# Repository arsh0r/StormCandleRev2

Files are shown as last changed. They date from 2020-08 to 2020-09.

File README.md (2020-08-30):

# StormCandleRev2 & Rev2b

An electronic candle measuring the air pressure and displaying it on a single, adressable RGBW LED.

An average air pressure is displayed by white light, high pressure in red and low pressure in blue.
The minimum and maximum pressure values are adapted automatically and stored in the EEPROM.

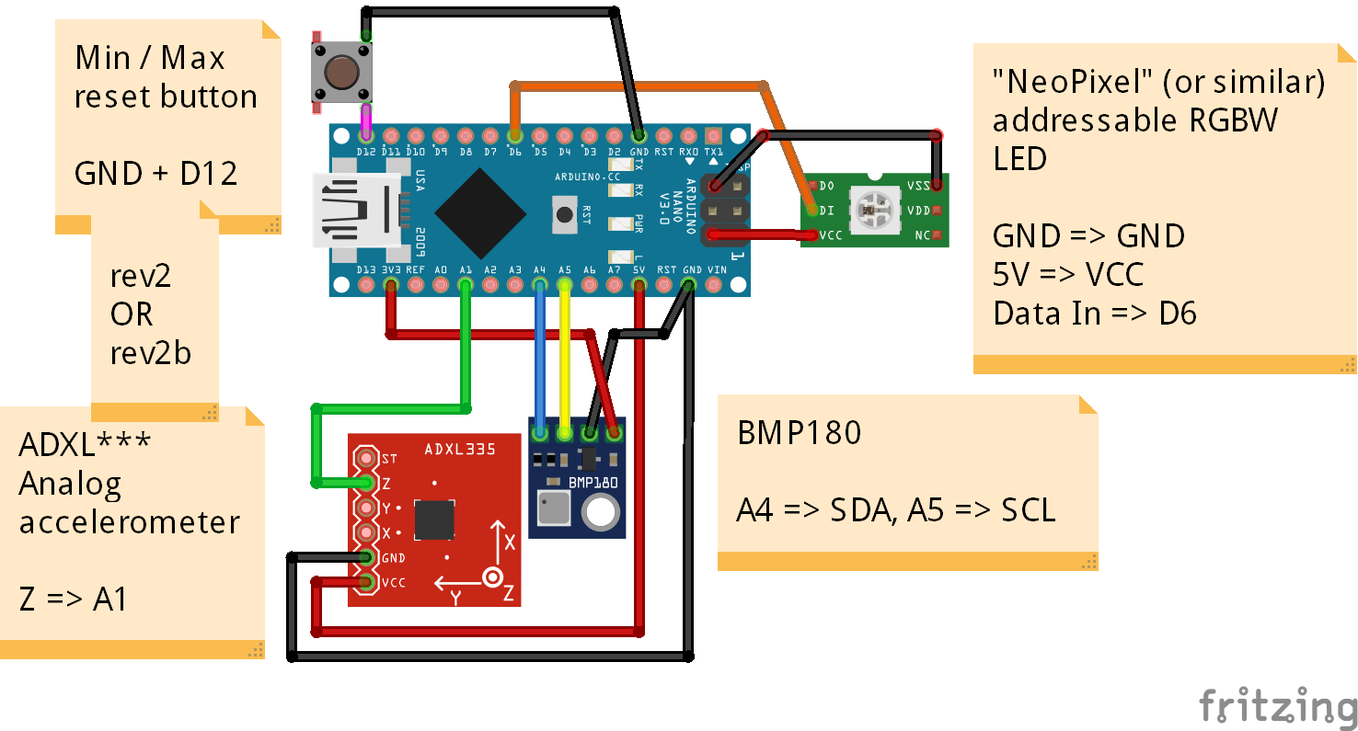
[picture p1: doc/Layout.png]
Frizzing sketch


This code works both with Revision 2 (reset button at the bottom) and Revision 2b (reset by accelerometer).

## Manuals

* [en English](/doc/manuals/en_manual.md)
* [de Deutsch](/doc/manuals/de_Benutzerhandbuch.md)

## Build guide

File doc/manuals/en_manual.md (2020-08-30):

# StormCandle User Manual
Thank you for ~~buying~~ building the StormCandle.

To help you enjoy your StormCandle, please read the following document carefully and follow its instructions.

## Understanding your StormCandle

Your StormCandle will show you the current air pressure as an intuitive color gradient.

It "remembers" the highest and lowes pressures it has ever experienced. At pressures in the centre between these values, it will glow warm white. 
At higher pressures, more and more red light is added, at lower pressures blue light. Since air pressure changes with altitude, 
you should perform a reset after any elevation change of more than one floor.

**Note:** If you operate the device in a roughly airtight environment such as a well-sealed house or appartment, 
you may accidentially change the air pressure when operating a strong range hood or other outward-facing ventilator. 
This may accidentially set a minimal pressure value far beneath the natural range and thus distort the displayed result. In this case, please perform a reset as explained below.

## Setup
To use the device, place it in a convenient location where you can see it and connect the USB plug to any USB power source (wall charger / USB power bank / computer). 
After first setup, you should perform a reset as described below.

### Resetting min / max values

#### Revision 2 (with reset button)
To perform a reset, first disconnect the device from power. Hold down the reset button (you may need to remove a cover at the bottom of the device to acces the button). While holding, connect the device to power and wait. 

#### Revision 2b (no reset button)
To perform a reset, first disconnect the device from power. Turn over the device and connect the device to power.

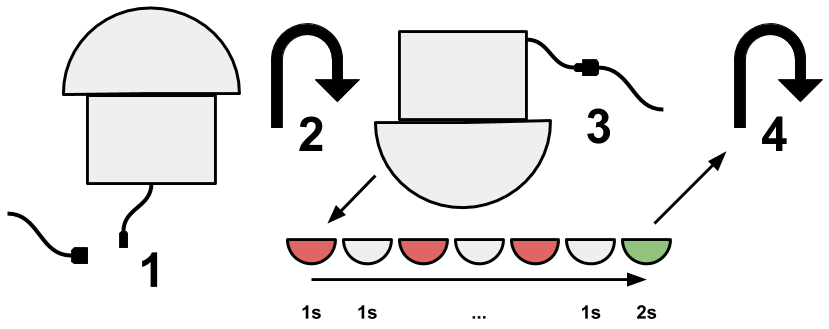
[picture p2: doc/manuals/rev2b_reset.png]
Rev2b reset process


The device will blink three times red (1 second) and once green (2 seconds). 
At the end of the green light, the device will be reset and start flickering white, blue and red.

## Technical information
Power consumption: ca. 50 mA @ 5 V

Source code: https://github.com/BitScout/StormCandleRev2

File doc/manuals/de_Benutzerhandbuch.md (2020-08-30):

# StormCandle Benutzerhandbuch
Herzlichen Glückwunsch zum ~~Kauf~~ Bau Ihrer StormCandle.
Damit Ihnen das Produkt viel Freude bereitet, lesen Sie bitte die folgenden Hinweise aufmerksam und befolgen Sie sie.

## Ihre StormCandle verstehen

Ihre StormCandle zeigt Ihnen den aktuellen Luftdruck intuitiv durch wechselnde Farben an.

Sie "merkt" sich den niedrigsten und höchsten Luftdruck, dem sie bisher ausgesetzt wurde.
Liegt  der Luftdruck genau mittig zwischen diesen Punkt leuchtet die StormCandle warmweiß.
Steigt der Luftdruck kommt stärker werdendes rotes Licht hinzu, bei niedrigerem Druck blaues Licht.
Da sich der Luftdruck mit der Höhe ändert, sollten Sie nach einer Ortsänderung des Gerätes von mehr als einem Stockwerk eine Rücksetzung vornehmen.

**Wichtig:** Falls Sie das Gerät in einem weitgehend luftdichten Umfeld wie z. B. einer Wohnung mit gut abgedichteten Fenstern und Türen betreiben, kann es passieren, dass beim Benutzen einer starken Dunstabzugshaube der Luftdruck deutlich unter das eigentliche Minimum fällt. Die StormCandle wird dies als neues Minimum registrieren und dementsprechend verfälschte Farben anzeigen. Bitte führen Sie in diesem Fall eine Rücksetzung wie unten beschrieben durch.

## Einrichtung
Zur Nutzung des Gerätes stellen Sie es bitte an einem gut einsehbaren Ort auf und verbinden Sie den USB-Stecker mit einer beliebigen USB-Stromquelle (USB-Ladegerät / Power Bank / Computer).
Nach der ersten Inbetriebnahme sollten Sie eine Rücksetzung durchführen (siehe unten).

### Höchst- und Tiefstwerte zurücksetzen

#### Revision 2 (Mit Reset-Knopf)
Um eine Rücksetzung durchzuführen, trennen Sie das Gerät bitte zunächst vom Strom. Halten Sie den Knopf an der Unterseite gedrückt. Ggf. müssen Sie hierzu eine Abdeckung entfernen. Während Sie den Knopf weiter gedrückt halten, verbinden Sie das Gerät mit der Stromzufuhr; halten Sie den Knopf weiter gedrückt.

#### Revision 2b (Ohne Reset-Knopf)
Um eine Rücksetzung durchzuführen, trennen Sie das Gerät bitte zunächst vom Strom. Drehen Sie die Lampe auf den Kopf und halten Sie sie so. Verbinden Sie das Gerät nun mit der Stromzufuhr.

Rev2b reset process

Die StormCandle blinkt dreimal rot (eine Sekunde Leuchtdauer) und anschließen einmal grün (zwei Sekunden). Sobald das grüne Licht erlischt sind die Höchst- und Tiefstwerte zurückgesetzt und die Lampe flackert in den Farben Warmweiß, Rot und Blau.
Das Flackern entsteht durch geringfügige Luftdruckschwankungen und lässt nach, sobald das Gerät höhere und niedriger Luftdrücke "erlernt" hat. Dies kann einige Stunden oder Tage dauern, während derer die Lampe **nicht** durchgehend in Betrieb sein muss.
Sie können das den Erfolg des Zurücksetzens testen, indem Sie die Lampe einen halben Meter anheben und absenken. Die Lichtfarbe sollte der Höhe entsprechend leicht rot bzw. blau werden.

## Technische Informationen
Energieverbrauch: ca. 50 mA @ 5 V (0,25 W)

Quellcode: https://github.com/BitScout/StormCandleRev2

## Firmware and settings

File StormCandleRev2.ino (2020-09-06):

// StormCandle Rev.2
// - For Ann -

// Displays the relative air pressure on a red (high) - blue (low) scale
// Self-learning, remembers the highest and lowest pressure it ever encountered
// Please perform a reset after significant elevation changes

// To reset the min/max values:
// 1. Power off the Arduino
// 2. Connect Pin 12 to ground (hold down the reset button)
// 3. Power on the Arduino
// 4. The LED will blink red three times
// 5. After one final green blink (2 seconds), the min/max values will be reset to just above and below the current measurement
// Note: With each reset, the memory addresses will be rotated through the EEPROM to reduce wear

// Connect the adressable RGBW LED to GND, to +5V and to PIN_LED

// Connect Arduino Nano -> pressure sensor BMP180
// A5  -> SCL
// A4  -> SDA
// GND -> GND
// VIN -> 3.3V

// EEPROM layout: (one letter = one byte)
// XXAAAABBBBCCCCDDDD
// I.L...L...L...L... (I = integer, L = long)
// XX   = Memory address
// AAAA = Minimum pressure at first run
// BBBB = Maximum pressure at first run
// CCCC = Minimum pressure after first reset
// DDDD = Maximum pressure after first reset
// etc.


#include <Wire.h>
#include <EEPROM.h>
#include <Adafruit_BMP085.h>
#include <Adafruit_NeoPixel.h>

Adafruit_BMP085 bmp;

//#define DEBUG 1

#define PIN_LED 6 // D6
#define PIN_RESET_EEPROM 12 // D12
#define PIN_ACCEL_Z A1
#define ACCEL_TRESHOLD 400
#define MEDIAN_COUNT 7 // Number of measurements per loop
#define STARTUP_RANGE 20 // Distance (in Pascale) between initial measurement and maximum / minimum at first startup
#define COLOR_BRIGHTNESS_FACTOR 1 // Make the color LEDs less bright
#define WHITE_BRIGHTNESS_FACTOR 0.1 // Make the white LED less bright

// Misc
int i;
int iMedian;
bool initializing = false;
unsigned long timestamp_last_readout;

bool firstrun = false; //first run;
float cycletime; //cycle time in [ms]
unsigned long micros_last; //last micros() in ms

// Pressures
long pa_measurements[MEDIAN_COUNT]; 
long pa_current;
float pa_current_PT1;
long pa_max;
long pa_min;
long pa_center;

// Manual inputs
bool switch_reset_eeprom;
int  acceleration_z;

// Addresses
int addr_int_addresses_start; // Start of the currently used address space
int addr_long_hpa_min;
int addr_long_hpa_max;
int address_block_end; // The first address after all used addresses

// LED
float led_max = 255;
int   red  = 0;
int   blue = 0;

Adafruit_NeoPixel strip = Adafruit_NeoPixel(1, PIN_LED, NEO_RGBW + NEO_KHZ800);


void setup() {
  setupHardware();

  timestamp_last_readout = millis();

  // First pressure measurement
  iMedian = MEDIAN_COUNT / 2;
  do {
    pa_current = bmp.readPressure();
  } while (pa_current < 900);

  EEPROM.get(0, addr_int_addresses_start);

  // Handle first launch
  if(-1 == addr_int_addresses_start) {
    initializing = true;
    addr_int_addresses_start = sizeof(int); // Leave the first two bytes in EEPROM for the start address of the min/max values
    EEPROM.put(0, addr_int_addresses_start);
  }

  // Check for reset button
  readResetSwitch();

  if(switch_reset_eeprom) {
    for(i = 0; i < 3; i++) {
      setColor(255, 0, 0, 0);
      delay(1000);
      setColor(0, 0, 0, 0);
      delay(1000);
    }

    // Read value again (to be sure)
    readResetSwitch();

    if(switch_reset_eeprom) {
      setColor(0, 255, 0, 0);
      delay(2000);

      // Add up all addresses as they were used before, then start after that. Addresses will be calculated again just below.
      calculateAddresses();
      addr_int_addresses_start = address_block_end;

      // Handle memory address wrap around
      if((E2END - 2*sizeof(long)) <= addr_int_addresses_start) {
        addr_int_addresses_start = sizeof(int);
      }
      
      EEPROM.put(0, addr_int_addresses_start); // Save the memory address to the beginning of the EEPROM memory
      initializing = true;
    }

      setColor(0, 0, 0, 0);
  }

  calculateAddresses();

  if(initializing) {
    #ifdef DEBUG
      Serial.println("Initializing EEPROM with current min/max values");
    #endif
    
    pa_max = pa_current + STARTUP_RANGE;
    pa_min = pa_current - STARTUP_RANGE;
    pa_center = pa_current;
    
    EEPROM.put(addr_long_hpa_min, pa_min);
    EEPROM.put(addr_long_hpa_max, pa_max);
  } else {
    #ifdef DEBUG
      Serial.println("Loading min/max values from EEPROM");
    #endif

    EEPROM.get(addr_long_hpa_min, pa_min);
    EEPROM.get(addr_long_hpa_max, pa_max);
  }

  calculateCenter();
  
  //init cycle time measurement
  micros_last = micros();
  firstrun = true;
}
  
void loop() {
  calcCycleTime();
  
  measureAndCalculatePT1();
  setLed();
  outputPressureOverSerial();

  #ifdef DEBUG
    //debugAddresses();
    //debugButton();
    //debugAcceleration();
    //debugLeds();
    debugPressures();
    Serial.println("");    
  #endif
  firstrun = false;
}

void setupHardware() {
  Serial.begin(9600);
  strip.begin();
  pinMode(PIN_RESET_EEPROM, INPUT_PULLUP);
  
  if (!bmp.begin()) {
    #ifdef DEBUG
      Serial.println("Sensor not found");
    #endif
    
    while (1) {}
  }
}

void calculateAddresses() {
  addr_long_hpa_min = addr_int_addresses_start;
  addr_long_hpa_max = addr_long_hpa_min + sizeof(long);
  address_block_end = addr_long_hpa_max + sizeof(long);
}

void readResetSwitch() {
  switch_reset_eeprom = !digitalRead(PIN_RESET_EEPROM);
  acceleration_z = analogRead(PIN_ACCEL_Z);

  if(acceleration_z > ACCEL_TRESHOLD) {
    switch_reset_eeprom = true;
  }
}

void measureAndCalculate() {
  // Collect measurements
  for (i = 0; i < MEDIAN_COUNT; i++) {
    do {
      pa_measurements[i] = bmp.readPressure();
    } while (pa_measurements[i] < 900);
  }

  // Sort measurements to find the median (center) value(s)
  bubbleSort();
  
  // Average the 3 central values to avoid excess flickering
  pa_current = (pa_measurements[iMedian] + pa_measurements[iMedian - 1] + pa_measurements[iMedian + 1]) / 3;

  // Calculate minimum, maximum and center values
  if(pa_current > pa_max) {
    pa_max = pa_current;
    EEPROM.put(addr_long_hpa_max, pa_max);
  }
  
  if(pa_current < pa_min) {
    pa_min = pa_current;
    EEPROM.put(addr_long_hpa_min, pa_min);
  }
  
  calculateCenter();
}

void calculateCenter() {
  pa_center = pa_min + (pa_max - pa_min) / 2;
}

void setLed() {
  // Set LED colours
  if (pa_current <= pa_center) red = 0; else red = led_max * (pa_current - pa_center) / (pa_max - pa_center);
  if (pa_current >= pa_center) blue = 0; else blue = led_max - (led_max * (pa_current - pa_min) / (pa_center - pa_min));

  setColor(red * COLOR_BRIGHTNESS_FACTOR, 0, blue * COLOR_BRIGHTNESS_FACTOR, led_max * WHITE_BRIGHTNESS_FACTOR);
}

void outputPressureOverSerial() {
  if(millis() - timestamp_last_readout > 60000) {
    timestamp_last_readout = millis();
    Serial.print(pa_current);
    Serial.println("");
  }
}

void setColor(int r, int g, int b, int w) {
  strip.setPixelColor(0, strip.Color(g, r, b, w));
  strip.show();
}

// Copied and adapted from https://www.tigoe.com/pcomp/code/arduinowiring/42/
void bubbleSort() {
  long out, in, swapper;
  
  for (out=0 ; out < MEDIAN_COUNT; out++) {
    for (in=out; in<(MEDIAN_COUNT-1); in++) {
      if ( pa_measurements[in] > pa_measurements[in+1] ) {
        swapper = pa_measurements[in];
        pa_measurements [in] = pa_measurements[in+1];
        pa_measurements[in+1] = swapper;
      }
    }
  }
}

void calcCycleTime() {
  unsigned long micros_current; //current lifetime in [us]
  
  //generate cycle time  
  micros_current = micros();
  if (micros_current >= micros_last) {
    cycletime = float(micros_current - micros_last) / 1000;
  }
  else { //micros() overflows approximately every 72 minutes.
    cycletime = float(0xFFFFFF - micros_last + micros_current) / 1000;
  }
  micros_last = micros_current;
}

void PT1(float in, float T, float &out) {
  float out_diff;
  float diff_T;

  if (firstrun) {
    out = in;
  } 
  else {
    out_diff = in - out;
    diff_T = abs(cycletime / T);
    if (diff_T < 1) {
      out = out + (out_diff * diff_T);
    }
    else {
      out = in;
    }
    if (abs(out) < 1.0e-7) {
      out = 0.0;
    }
  }
}

void measureAndCalculatePT1() {
  long pa_measurement;
  
  // Collect measurements
  do {
    pa_measurement = bmp.readPressure();
  } while (pa_measurement < 900);

  PT1(pa_measurement, 2000.0, pa_current_PT1);

  pa_current = pa_current_PT1;

  // Calculate minimum, maximum and center values
  if(pa_current > pa_max) {
    pa_max = pa_current;
    EEPROM.put(addr_long_hpa_max, pa_max);
  }
  
  if(pa_current < pa_min) {
    pa_min = pa_current;
    EEPROM.put(addr_long_hpa_min, pa_min);
  }
  
  calculateCenter();
}

#ifdef DEBUG
  void debugAddresses() {
    Serial.print(addr_int_addresses_start);
    Serial.print("\t");
    Serial.print(addr_long_hpa_min);
    Serial.print("\t");
    Serial.print(addr_long_hpa_max);
  }
  
  void debugButton() {
    switch_reset_eeprom = !digitalRead(PIN_RESET_EEPROM);
    Serial.print(switch_reset_eeprom);
  }

  void debugAcceleration() {
    acceleration_z = analogRead(PIN_ACCEL_Z);
    Serial.print(acceleration_z);
  }
  
  void debugLeds() {
    Serial.print(blue);
    Serial.print("\t");
    Serial.print(red);
    Serial.print("\t");
    Serial.print(0);
    Serial.print("\t");
    Serial.print(255);
  }
  
  void debugPressures() {
    Serial.print(pa_current);
    Serial.print("\t");
    Serial.print(pa_min);
    Serial.print("\t");
    Serial.print(pa_max);
    Serial.print("\t");
    Serial.print(pa_center);
  }
#endif

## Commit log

2020-06-17 Specified that a RGBW LED is actually needed.
    [Layout.fzz]
2020-08-29 Added alternative reset method via analog accelerometer
    [Layout.fzz]
2020-08-30 Added Rev2b documentation
    [Layout.fzz]
2020-08-31 Added serial pressure printout every 60 seconds
2020-09-06 use PT1 element for damping of the pressure sensor values
2020-09-12 add logged data
    [200906_stormcandle.csv, 200907_stormcandle.csv, 200908_stormcandle.csv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]
